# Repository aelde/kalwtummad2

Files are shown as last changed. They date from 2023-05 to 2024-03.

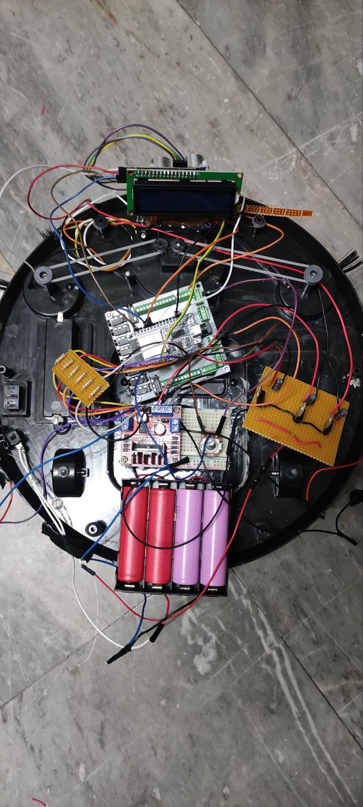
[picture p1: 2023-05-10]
model/pic/view2.jpeg

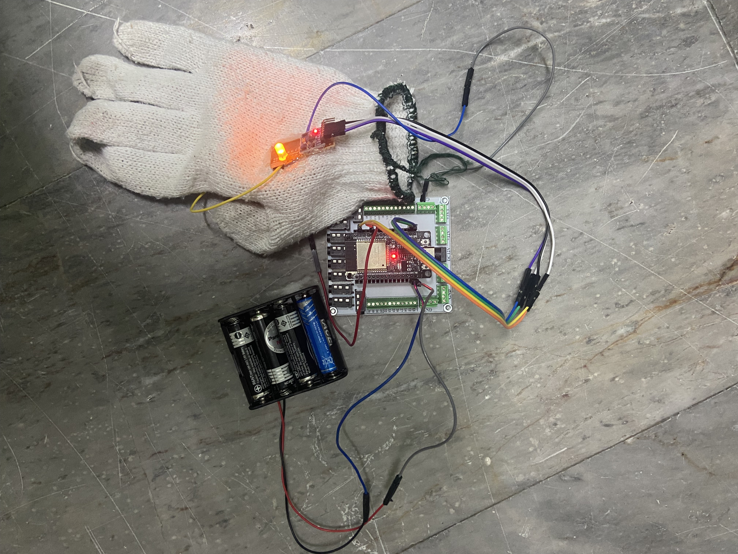
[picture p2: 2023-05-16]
model/pic/hand control.jpg

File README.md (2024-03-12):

# kalwtummad2
# mini robot


**car robot control over wifi / control over hand using mqtt**\
3d : <https://collaborate.shapr3d.com/v/xkKrqxI_4FUdMemtdK0US>

โปรเจคนี้เกิดจากความสนใจใน esp32 ของผมและพอดีช่วงนั้นอาจารย์มีหุ่นยนต์ดูดฝุ่นราคาถูกที่ไม่ได้ใช้อยู่ตัวนึง และพอดีกับที่ผมมี mpu6050 อยู่ที่บ้านพอดี ผมเลยเกิดไอเดียที่จะสร้างหุ่นยนต์ที่บังคับด้วยการขยับของมือขึ้นมา
เริ่มจากการที่แกะชิ้นส่วนทั้งหมดออกแล้วก็เอาอุปกรณ์ใหม่ใส่เข้าไปแทนหมด แล้วจากนั้นก็เชื่อมอุปกรณ์ทั้งหมดกับ esp32 จนเกิดเป็นหุ่นย์นี้ขึ้นมา(kalwtummad) โดยหุ่นย์นี้จะบังคับด้วยมือผ่าน mqtt และยังสามารถบังคับผ่านหน้า dashboard ได้ด้วย

อุปกรณ์หลักๆใน project
  - esp32
  - mpu6050
  - l298n
  - lcd1602
  - I2C liquid crystal displays

การใช้งาน : หมุนมือไปในทิศที่ต้องการจะให้รถวิ่ง ดูใน HOW_TO_USE.jpeg

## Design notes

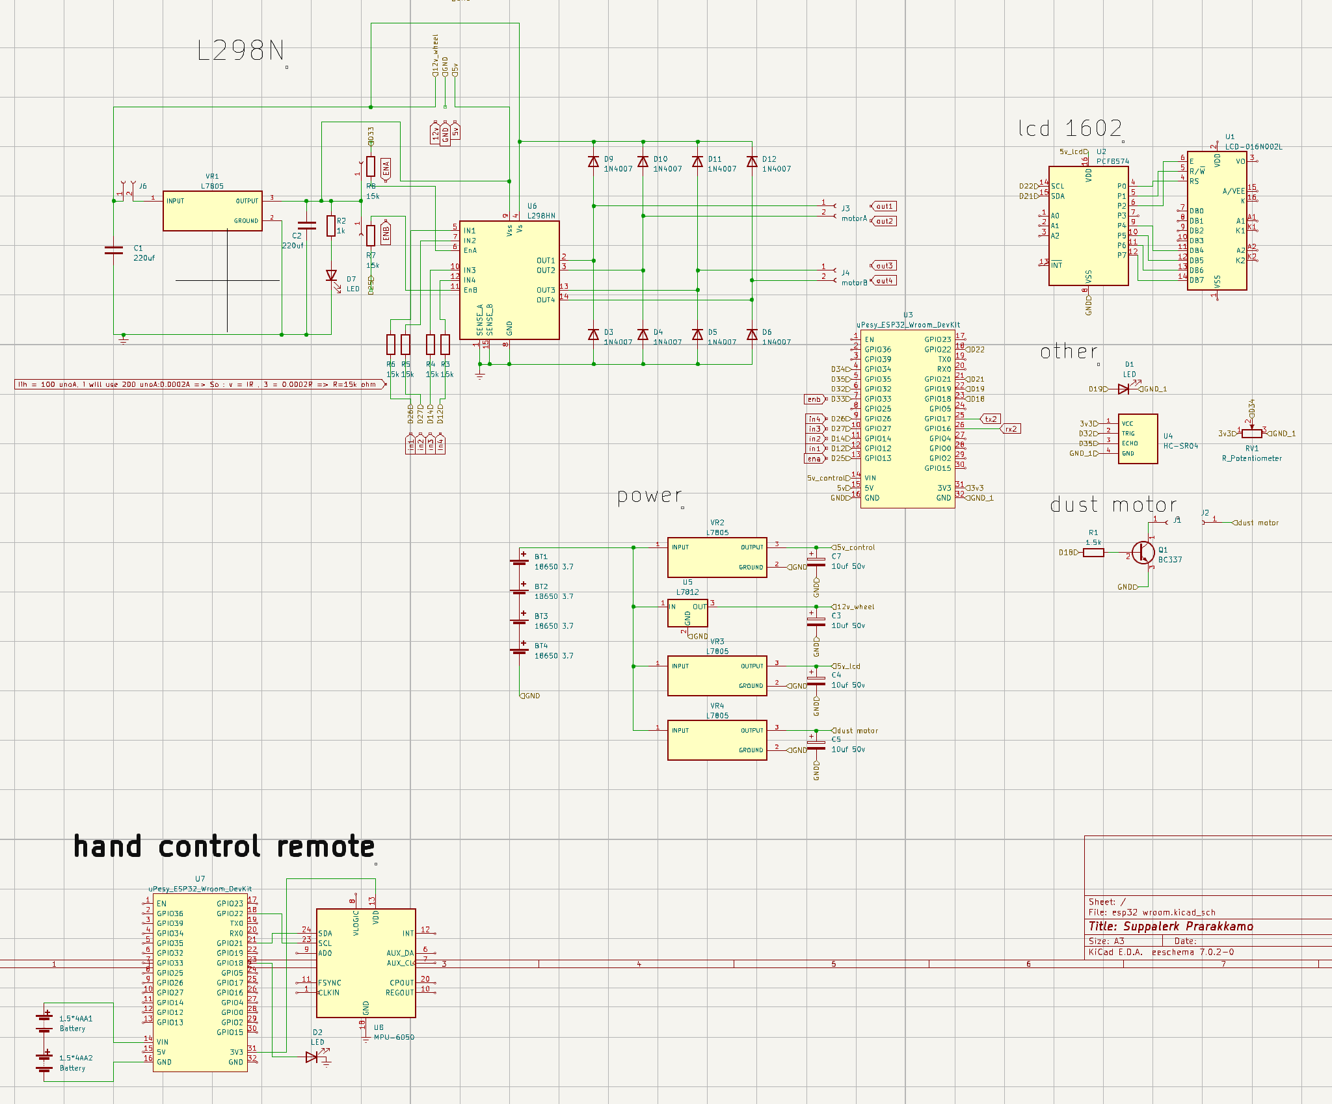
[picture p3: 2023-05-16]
model/pic/schematic updated.png

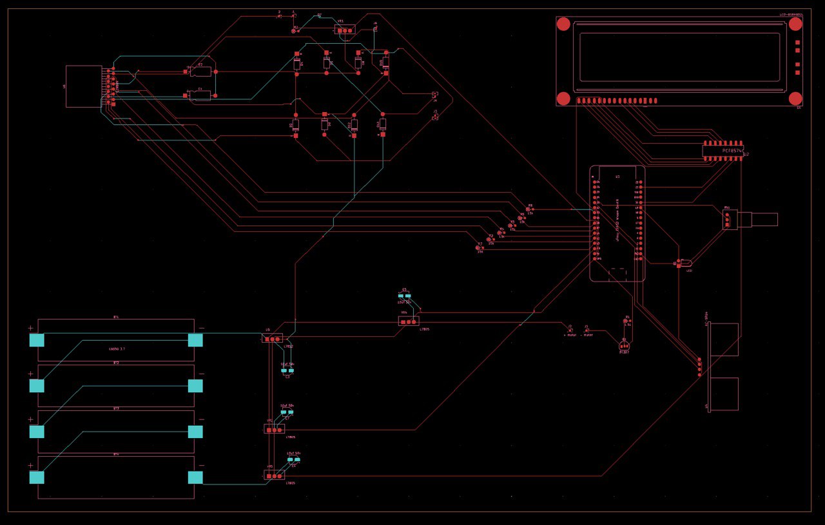
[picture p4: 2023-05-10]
model/pic/pcb.jpeg

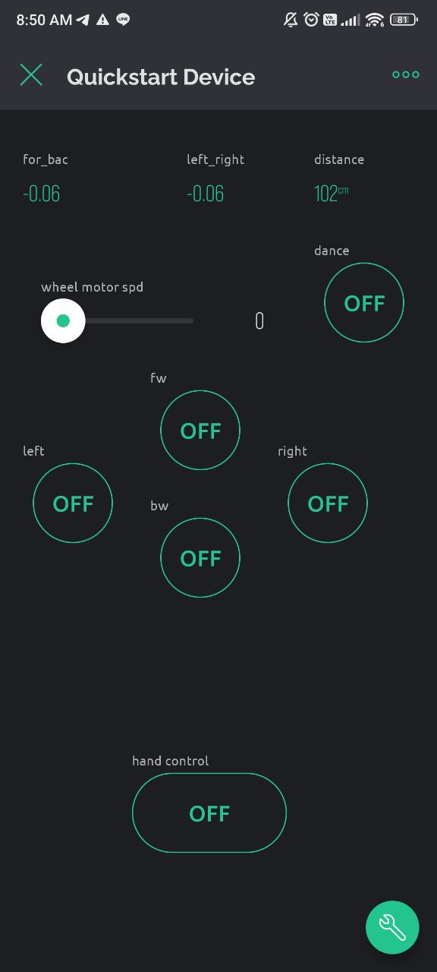
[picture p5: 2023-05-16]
model/pic/dash updated.jpeg

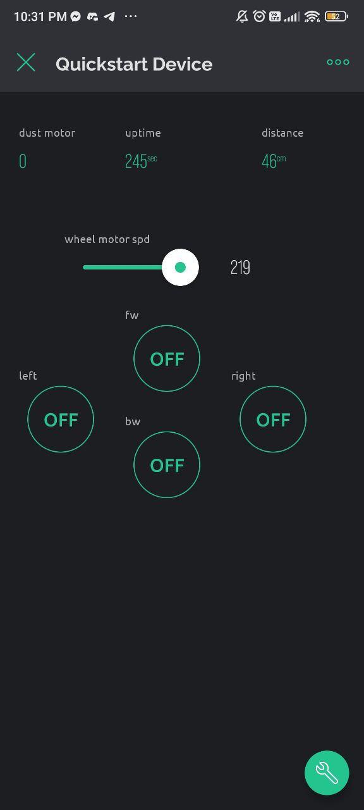
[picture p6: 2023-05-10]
model/pic/blynk dash.jpeg

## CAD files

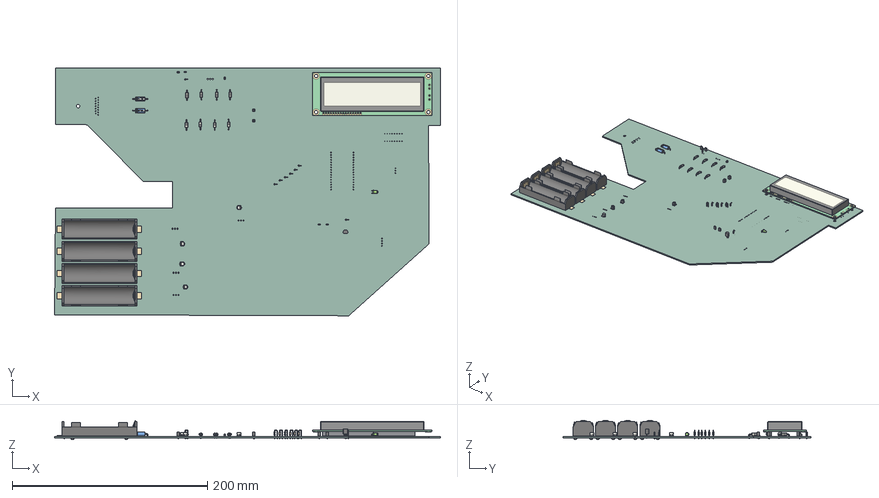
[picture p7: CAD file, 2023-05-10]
model/3d/pcb.step
395.2 x 253.5 x 19.8 mm
esp32 wroom PCB

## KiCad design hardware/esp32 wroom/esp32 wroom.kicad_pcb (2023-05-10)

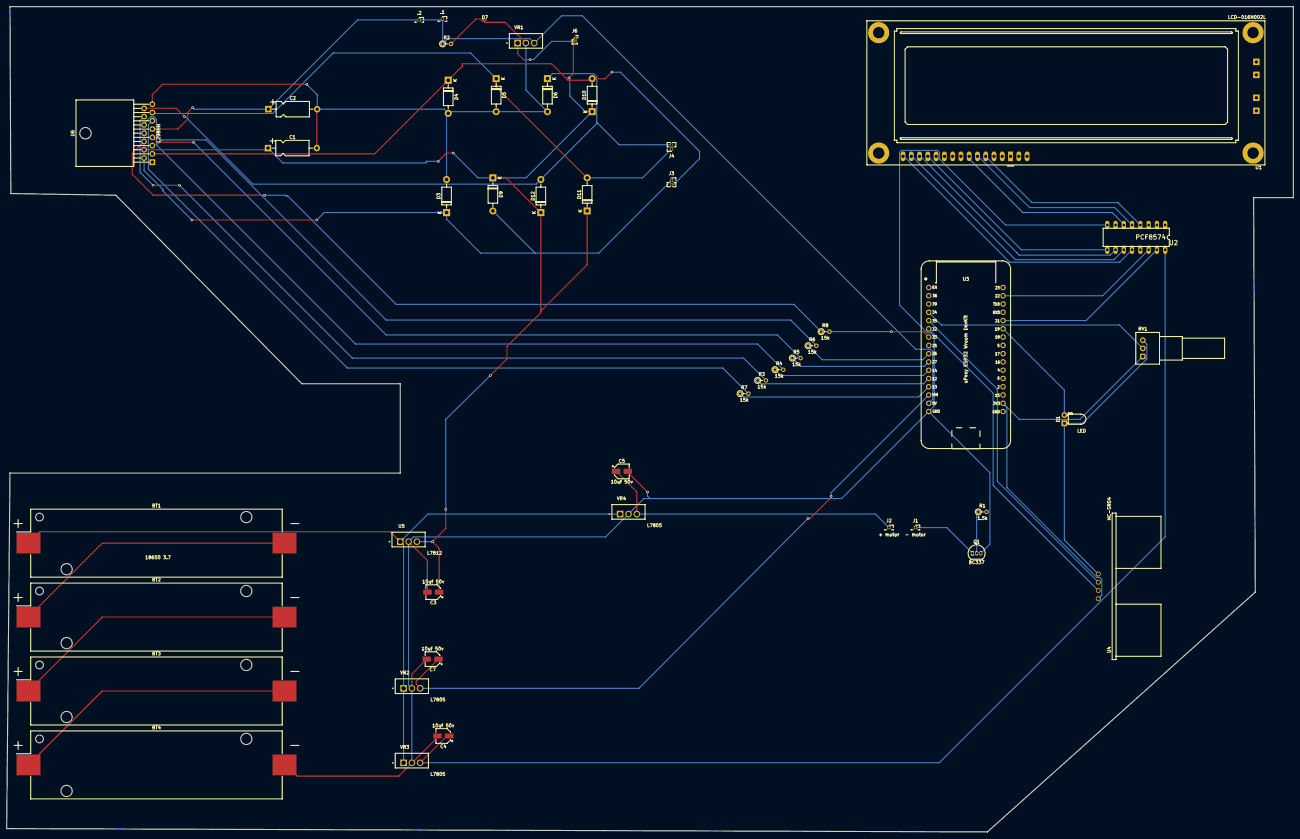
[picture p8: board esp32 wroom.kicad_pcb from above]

Board: 2 copper layers, 395.2 x 253.5 mm, 47 parts (0 on the bottom side), 47 nets.

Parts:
.1, .2: PinSocket_1x01_P1.27mm_Vertical
BT1, BT2, BT3, BT4: 18650 3.7; BatteryHolder_Keystone_1042_1x18650
C1, C2: 220uf; CP_Axial_L10.0mm_D4.5mm_P15.00mm_Horizontal
C3, C4, C5, C7: 10uf 50v; CP_Elec_4x3.9
D1: LED; LED_D3.0mm_Horizontal_O1.27mm_Z2.0mm
D3, D4, D5, D6, D9, D10, D11, D12: 1N4007; D_DO-41_SOD81_P10.16mm_Horizontal
D7: LED; LED_0201_0603Metric
J1: - motor; PinSocket_1x01_P1.27mm_Vertical
J2: + motor; PinSocket_1x01_P1.27mm_Vertical
J3: motorA; PinSocket_1x02_P1.27mm_Vertical
J4: motorB; PinSocket_1x02_P1.27mm_Vertical
J6: PinSocket_1x02_P1.00mm_Vertical
Q1: BC337; TO-92_Inline
R1: 1.5k; R_Axial_DIN0204_L3.6mm_D1.6mm_P2.54mm_Vertical
R2: 1k; R_Axial_DIN0204_L3.6mm_D1.6mm_P2.54mm_Vertical
R3, R4, R5, R6, R7, R8: 15k; R_Axial_DIN0204_L3.6mm_D1.6mm_P2.54mm_Vertical
RV1: R_Potentiometer; Potentiometer_Alps_RK097_Single_Horizontal
U1: LCD-016N002L
U2: PCF8574; DIL16
U3: uPesy_ESP32_Wroom_DevKit
U4: HC-SR04
U5: L7812; L7805
U6: L298HN; TO-220-15_P2.54x2.54mm_StaggerOdd_Lead5.84mm_TabDown
VR1, VR2, VR3, VR4: L7805

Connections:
5v: .1.1, .2.1, C2.1, R2.1, U3.15 (5V), U6.9 (Vss), VR1.3 (OUTPUT)
/3v3: RV1.1, U3.31 (3V3), U4.1 (VCC)
/5v_control: C7.1, U3.14 (VIN), VR2.3 (OUTPUT)
/5v_lcd: C4.1, U2.16 (VDD), VR3.3 (OUTPUT)
/12v_wheel: C1.1, C3.1, D9.1 (K), D10.1 (K), D11.1 (K), D12.1 (K), J6.1, U5.3 (OUT), U6.4 (Vs)
/D12: R3.1, U3.12 (GPIO12)
/D14: R4.1, U3.11 (GPIO14)
/D18: R1.2, U3.23 (GPIO18)
/D19: D1.2 (A), U3.22 (GPIO19)
/D21: U2.15 (SDA), U3.21 (GPIO21)
/D22: U2.14 (SCL), U3.18 (GPIO22)
/D25: R7.1, U3.13 (GPIO13)
/D26: R6.1, U3.9 (GPIO26)
/D27: R5.1, U3.10 (GPIO27)
/D32: U3.6 (GPIO32), U4.2 (TRIG)
/D33: R8.2, U3.7 (GPIO33)
/D34: RV1.2, U3.4 (GPIO34)
/D35: U3.5 (GPIO35), U4.3 (ECHO)
/GND_1: D1.1 (K), RV1.3, U3.32 (GND), U4.4 (GND)
/dust motor: C5.1, J2.1, VR4.3 (OUTPUT)
Earth: C1.2, C2.2, D3.2 (A), D4.2 (A), D5.2 (A), D6.2 (A), D7.1 (K), U6.1 (SENSE_A), U6.8 (GND), U6.15 (SENSE_B), VR1.2 (GROUND)
GND: BT4.2 (-), C3.2, C4.2, C5.2, C7.2, Q1.3 (E), U2.8 (VSS), U3.16 (GND), U5.2 (GND), VR2.2 (GROUND), VR3.2 (GROUND), VR4.2 (GROUND)
unnamed: BT1.1 (+), U5.1 (IN), VR2.1 (INPUT), VR3.1 (INPUT), VR4.1 (INPUT)
unnamed: BT1.2 (-), BT2.1 (+)
unnamed: BT2.2 (-), BT3.1 (+)
unnamed: BT3.2 (-), BT4.1 (+)
unnamed: D3.1 (K), D9.2 (A), J3.1, U6.2 (OUT1)
unnamed: D7.2 (A), R2.2
unnamed: D4.1 (K), D10.2 (A), J3.2, U6.3 (OUT2)
unnamed: D5.1 (K), D11.2 (A), J4.1, U6.13 (OUT3)
unnamed: D6.1 (K), D12.2 (A), J4.2, U6.14 (OUT4)
unnamed: J1.1, Q1.1 (C)
unnamed: J6.2, VR1.1 (INPUT)
unnamed: Q1.2 (B), R1.1
unnamed: U1.11 (DB4), U2.9 (P4)
unnamed: U1.12 (DB5), U2.10 (P5)
unnamed: U1.13 (DB6), U2.11 (P6)
unnamed: U1.14 (DB7), U2.12 (P7)
unnamed: U1.6 (E), U2.6 (P2)
unnamed: U1.4 (RS), U2.4 (P0)
unnamed: U1.5 (R/~W), U2.5 (P1)
unnamed: R8.1, U6.6 (EnA)
unnamed: R7.2, U6.11 (EnB)
unnamed: R6.2, U6.5 (IN1)
unnamed: R5.2, U6.7 (IN2)
unnamed: R4.2, U6.10 (IN3)
unnamed: R3.2, U6.12 (IN4)

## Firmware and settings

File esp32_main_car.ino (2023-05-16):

#include <Arduino.h>
#include <LiquidCrystal_I2C.h>
#include "LittleFS.h"
#include <WiFiClientSecure.h>
#include <PubSubClient.h>

char msg[150];
long lastMsg = 0;
float x=0,y=0;

//mpu6050 import from another esp32 with blynk
int hand_control = 0;
float for_bac = 0; 
float left_right = 0;

// setup pin
long int duration;
int distance = 0;

// MQTT netpie  device 2 **********************
const char* mqtt_server = "broker.netpie.io";
const int mqtt_port = 1883;
const char* mqtt_Client = "";
const char* mqtt_username = "";
const char* mqtt_password = "";

WiFiClient espClient;
PubSubClient client(espClient);

void callback(char* topic, byte* payload, unsigned int length) {
  // Serial.print("Message arrived [");
  // Serial.print(topic);
  // Serial.print("] ");
  String message;
  for (int i = 0; i < length; i++) {
    message = message + (char)payload[i];
  }
  if (String(topic) == "@msg/test") {
    for_bac = message.toFloat();
  } else if (String(topic) == "@msg/test2") {
    left_right = message.toFloat();
  }
}

void reconnect() {
  while (!client.connected()) {
    Serial.print("Attempting NETPIE2020 connection…");
    if (client.connect(mqtt_Client, mqtt_username, mqtt_password)) {
      Serial.println("NETPIE2020 connected");
      // client.subscribe("@msg/led");
      client.subscribe("@msg/#");
      // client.subscribe("@msg/test2");
      
    }
    else {
      Serial.print("failed, rc=");
      Serial.print(client.state());
      Serial.println("try again in 5 seconds");
      delay(5000);
    }
  }
}
// **********************************************************************************************************************************************************

// wheel motor l298n
int wheel_spd = 0;
int enA = 13; // 12 // 33  // 13
int in1 = 12; // 14 // 26  // 12
int in2 = 14; // 13 // 27  // 14
int in3 = 27; // 26 // 14  // 26
int in4 = 26; // 33 // 12  // 33
int enB = 33; // 27 // 13  // 27

// status robot control move forward, backward, left, right, autopilot
int fw = 0, bw = 0, right = 0, left = 0, autopilot = 0;

// potentiometer
int pot = 34;
int pwm = 0;

// Lcd
int scl = 22;
int sda = 21;
LiquidCrystal_I2C lcd(0x27, 16, 2); // 0x27 for PCF8574 and 0x3F for PCF8574A

// ultrasonic
int t = 32;
int e = 35;

int led1 = 19;
int dust = 18; 

// dance mode
int dance = 0;

void lcdsetup(){
  lcd.init();
  lcd.backlight();
}
void lcdrefresh(int agr, int lcdrow){
  float lcdcon = agr/10;
  if(lcdcon < 1){lcd.setCursor(5,lcdrow);}
  else if(lcdcon < 10){lcd.setCursor(6,lcdrow);}
  else if(lcdcon < 100){lcd.setCursor(7,lcdrow);}
  else if(lcdcon < 1000){lcd.setCursor(8,lcdrow);}
  lcd.print("                ");
}
void move(int fw, int bw, int right, int left){
  if(fw == 1){
    Serial.println("move forward");
    analogWrite(enA, wheel_spd);
    analogWrite(enB, wheel_spd);
    digitalWrite(in1, 1);
    digitalWrite(in2, 0);
    digitalWrite(in3, 1);
    digitalWrite(in4, 0);
  }
  else if(bw == 1){
    Serial.println("move backward");
    analogWrite(enA, wheel_spd);
    analogWrite(enB, wheel_spd);
    digitalWrite(in1, 0);
    digitalWrite(in2, 1);
    digitalWrite(in3, 0);
    digitalWrite(in4, 1);
  }
  else if(right == 1){
    Serial.println("move right");
    analogWrite(enA, wheel_spd);
    analogWrite(enB, wheel_spd);
    digitalWrite(in1, 0);
    digitalWrite(in2, 1);
    digitalWrite(in3, 1);
    digitalWrite(in4, 0);
  }
  else if(left == 1){
    Serial.println("move left");
    analogWrite(enA, wheel_spd);
    analogWrite(enB, wheel_spd);
    digitalWrite(in1, 1);
    digitalWrite(in2, 0);
    digitalWrite(in3, 0);
    digitalWrite(in4, 1);
  } else if (dance == 1){
      for (int i = 0; i < 3; i++) {
          digitalWrite(led1, HIGH);
          delay(250);
          digitalWrite(led1, LOW);
          delay(250);
      }
    Serial.println("dance");
    analogWrite(enA, 240);
    analogWrite(enB, 240);
    // spin
    digitalWrite(in1, 1);
      digitalWrite(led1,HIGH);
    digitalWrite(in2, 0);
      digitalWrite(led1,LOW);
    digitalWrite(in3, 0);
      digitalWrite(led1,HIGH);
    digitalWrite(in4, 1);
    delay(4000);

    digitalWrite(led1,LOW);
    // spin
    digitalWrite(in1, 0);
    digitalWrite(led1,HIGH);
    digitalWrite(in2, 1);
    digitalWrite(led1,LOW);
    digitalWrite(in3, 1);
    digitalWrite(led1,HIGH);
    digitalWrite(in4, 0);
    delay(4000);

    digitalWrite(led1,LOW);
    for (int i = 0; i < 3; i++) {
          digitalWrite(led1, HIGH);
          delay(100);
          digitalWrite(led1, LOW);
          delay(100);
      }
    // forward a  bit
    digitalWrite(in1, 1);
    digitalWrite(in2, 0);
    digitalWrite(in3, 1);
    digitalWrite(in4, 0);
      delay(1000);

    for (int i = 0; i < 5; i++) {
          digitalWrite(led1, HIGH);
          delay(50);
          digitalWrite(led1, LOW);
          delay(50);
      }
      digitalWrite(led1,HIGH);
    // backward a bit
    digitalWrite(in1, 0);
    digitalWrite(in2, 1);
    digitalWrite(in3, 0);
    digitalWrite(in4, 1);
      delay(1000);
      digitalWrite(led1,LOW);

  }
  else{
    Serial.println("stop");
    analogWrite(enA, 0);
    analogWrite(enB, 0);
    digitalWrite(in1, LOW);
    digitalWrite(in2, LOW);
    digitalWrite(in3, LOW);
    digitalWrite(in4, LOW);
  }
}
void hand_controller(){
    if (abs(for_bac) >= abs(left_right)){
        wheel_spd = abs(for_bac);
        if (for_bac > 0){
            fw = 1;
            bw = 0;
            right = 0;
            left = 0;
            dance = 0;
        } else {
            fw = 0;
            bw = 1;
            right = 0;
            left = 0;
            dance = 0;
        }
    } else {
        wheel_spd = abs(left_right);
        if (left_right > 0){
            fw = 0;
            bw = 0;
            right = 1;
            left = 0;
            dance = 0;
        } else {
            fw = 0;
            bw = 0;
            right = 0;
            left = 1;
            dance = 0;
        }
    }
    move(fw, bw, right, left);
    Serial.println("Wheel speed : "+String(wheel_spd));

}
// **********************************************************************************************************************************************************
/*************************************************************

  This is a simple demo of sending and receiving some data.
  Be sure to check out other examples!
 *************************************************************/

/* Fill-in information from Blynk Device Info here */
#define BLYNK_TEMPLATE_ID           ""
#define BLYNK_TEMPLATE_NAME         ""
#define BLYNK_AUTH_TOKEN            ""

/* Comment this out to disable prints and save space */
#define BLYNK_PRINT Serial


#include <WiFi.h>
#include <WiFiClient.h>
#include <BlynkSimpleEsp32.h>

// Your WiFi credentials.

//char ssid[] = "SIAM_WIFI";
//char pass[] = "";

BlynkTimer timer;

// This function is called every time the Virtual Pin 0 state changes
BLYNK_WRITE(V0)
{
  // Set incoming value from pin V0 to a variable
  int value = param.asInt();
  dance = value;
}
BLYNK_WRITE(V4)
{
  // Set incoming value from pin V0 to a variable
  int value = param.asInt();
  wheel_spd = value;
}
BLYNK_WRITE(V6)
{
  // Set incoming value from pin V0 to a variable
  int value = param.asInt();
  fw = value;
}
BLYNK_WRITE(V7)
{
  // Set incoming value from pin V0 to a variable
  int value = param.asInt();
  bw = value;
}
BLYNK_WRITE(V8)
{
  // Set incoming value from pin V0 to a variable
  int value = param.asInt();
  left = value;
}
BLYNK_WRITE(V9)
{
  // Set incoming value from pin V0 to a variable
  int value = param.asInt();
  right = value;
}

// hand control
BLYNK_WRITE(V1)
{
  // Set incoming value from pin V0 to a variable
  int value = param.asInt();
  hand_control = value;
}
// BLYNK_WRITE(V2)
// {
//   // Set incoming value from pin V0 to a variable
// //   int value = param.asInt();
//   double value = param.asDouble();
//   for_bac = value;
// }
// BLYNK_WRITE(V5)
// {
//   // Set incoming value from pin V0 to a variable
//     //   int value = param.asInt();
//     double value = param.asDouble();
//     left_right = value;
// }

// This function is called every time the device is connected to the Blynk.Cloud
// BLYNK_CONNECTED()
// {
//   // Change Web Link Button message to "Congratulations!"
//   Blynk.setProperty(V3, "offImageUrl", "https://static-image.nyc3.cdn.digitaloceanspaces.com/general/fte/congratulations.png");
//   Blynk.setProperty(V3, "onImageUrl",  "https://static-image.nyc3.cdn.digitaloceanspaces.com/general/fte/congratulations_pressed.png");
//   Blynk.setProperty(V3, "url", "https://docs.blynk.io/en/getting-started/what-do-i-need-to-blynk/how-quickstart-device-was-made");
// }

// This function sends Arduino's uptime every second to Virtual Pin 2.
void myTimerEvent()
{
  // You can send any value at any time.
  // Please don't send more that 10 values per second.
  // Blynk.virtualWrite(V2, millis() / 1000);
  // Blynk.virtualWrite(V5, pwm);
  Blynk.virtualWrite(V3, distance);
}

// **********************************************************************************************************************************************************
void setup(){
  Serial.begin(115200);
  Serial.println("setup...");
  // blink setup ***********
  Blynk.begin(BLYNK_AUTH_TOKEN, ssid, pass);
  // You can also specify server:
  // Blynk.begin(BLYNK_AUTH_TOKEN, ssid, pass, "blynk.cloud", 80);
  // Blynk.begin(BLYNK_AUTH_TOKEN, ssid, pass, "blynk.cloud", 8080);
  // Setup a function to be called every second
  timer.setInterval(1000L, myTimerEvent);
  // ***********************

    // mqtt setup ************
    client.setServer(mqtt_server, mqtt_port);
    client.setCallback(callback);
    // ***********************

//   pinMode(dust, OUTPUT);
  pinMode(enA, OUTPUT);
  pinMode(enB, OUTPUT);
  pinMode(in1, OUTPUT);
  pinMode(in2, OUTPUT);
  pinMode(in3, OUTPUT);
  pinMode(in4, OUTPUT);

  pinMode(scl, OUTPUT);
  pinMode(sda, OUTPUT);
  pinMode(t, OUTPUT);
  pinMode(e, INPUT);
  pinMode(led1, OUTPUT);

  lcdsetup();
    for (int i = 0; i < 5; i++) {
    digitalWrite(led1, HIGH);
    delay(250);
    digitalWrite(led1, LOW);
    delay(250);
    }

  Serial.println("setup...end");
}
void loop(){
    //   Serial.println("loop...");
    Blynk.run();
    //   Serial.println("Blynk.run()...end");
    // Serial.println("wheel : "+String(wheel_spd));
    timer.run();

    if (for_bac > 250){for_bac = 250;}
    if (for_bac < -250){for_bac = -250;}
    if (left_right > 250){left_right = 250;}
    if (left_right < -250){left_right = -250;}
    
    if (!client.connected()) {
        reconnect();
    }
    client.loop();

    long now = millis();

    if (now - lastMsg > 500) {
    Serial.println("for_bac : "+String(abs(for_bac)));
    Serial.println("left_right : "+String(abs(left_right)));
    lastMsg = now;
    }
    delay(1); 

  // analogWrite(enA, wheel_spd);
  // digitalWrite(in1, 1);
  // digitalWrite(in2, 0);

    digitalWrite(t, LOW);
    delayMicroseconds(2);
    // Sets the trigPin on HIGH state for 10 micro seconds
    digitalWrite(t, HIGH);
    delayMicroseconds(10);
    digitalWrite(t, LOW);
    // Reads the echoPin, returns the sound wave travel time in microseconds
    duration = pulseIn(e, HIGH);
    // Calculating the distance
    distance = duration * 0.034 / 2;
    //   Serial.print("Distance: ");
    //   Serial.println(distance);

    // function to real time update the distance ไม่ให้ตัวเลขทับกัน
    lcdrefresh(distance, 1);
    if(distance < 15){
        digitalWrite(led1, HIGH);
    }
    else{
        digitalWrite(led1, LOW);
    }
    lcd.setCursor(0, 1);
    lcd.print("Dis:");
    lcd.print(distance);

    //   int p = analogRead(pot);
    //   pwm = map(p, 0, 4095, 0, 255);
    //   Serial.print("PWM:");
    //   Serial.println(pwm);
    lcdrefresh(wheel_spd, 0);
    lcd.setCursor(0, 0);
    lcd.print("SPD:");
    lcd.print(wheel_spd);

    //   Serial.println("move...");
    Serial.println("hand_control : "+String(hand_control));
    if (hand_control == 1)
    {
        // Serial.println("hand control...");
        hand_controller();
        Serial.println("for_bac : "+String(for_bac));
        Serial.println("left_right : "+String(left_right));
    } else {
        move(fw, bw, right, left);
        // move(fw, bw, right, left);

    }
    
    //   Serial.println("move...end");
    
    // digitalWrite(led1, HIGH);
    
    //   analogWrite(dust, pwm);

    // Serial.println("a:" + String((dust)));
    // ledcAttachPin(dust, pwm);
    //   Serial.println("loop...end");
    delay(1);
}

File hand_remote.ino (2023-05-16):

#include <WiFiClientSecure.h>
#include <Wire.h>
#include <PubSubClient.h>
#include <WiFi.h>

int led = 18;
char msg[150];

// MQTT netpie device 3 **********************
const char* mqtt_server = "broker.netpie.io";
const int mqtt_port = 1883;
const char* mqtt_Client = "";
const char* mqtt_username = "";
const char* mqtt_password = "";

WiFiClient espClient;
PubSubClient client(espClient);

void reconnect() {
  while (!client.connected()) {
    Serial.print("Attempting NETPIE2020 connection…");
    if (client.connect(mqtt_Client, mqtt_username, mqtt_password)) {
      Serial.println("NETPIE2020 connected");
    } else {
      Serial.print("failed, rc=");
      Serial.print(client.state());
      Serial.println("try again in 5 seconds");
      delay(5000);
    }
  }
}

// mpu 6050
float RateRoll, RatePitch, RateYaw;
float AccX, AccY, AccZ;
float AngleRoll, AnglePitch;
float LoopTimer;

double x = 0, y = 0, z = 0;

int pot = 34;
int a = 0;

// mp6050 setup
void gyro_signals(void) {
  Wire.beginTransmission(0x68);
  Wire.write(0x1A);
  Wire.write(0x05);
  Wire.endTransmission();
  Wire.beginTransmission(0x68);
  Wire.write(0x1C);
  Wire.write(0x10);
  Wire.endTransmission();
  Wire.beginTransmission(0x68);
  Wire.write(0x3B);
  Wire.endTransmission();
  Wire.requestFrom(0x68, 6);
  int16_t AccXLSB = Wire.read() << 8 | Wire.read();
  int16_t AccYLSB = Wire.read() << 8 | Wire.read();
  int16_t AccZLSB = Wire.read() << 8 | Wire.read();
  Wire.beginTransmission(0x68);
  Wire.write(0x1B);
  Wire.write(0x8);
  Wire.endTransmission();
  Wire.beginTransmission(0x68);
  Wire.write(0x43);
  Wire.endTransmission();
  Wire.requestFrom(0x68, 6);
  int16_t GyroX = Wire.read() << 8 | Wire.read();
  int16_t GyroY = Wire.read() << 8 | Wire.read();
  int16_t GyroZ = Wire.read() << 8 | Wire.read();
  RateRoll = (float)GyroX / 65.5;
  RatePitch = (float)GyroY / 65.5;
  RateYaw = (float)GyroZ / 65.5;
  AccX = (float)AccXLSB / 4096;
  AccY = (float)AccYLSB / 4096;
  AccZ = (float)AccZLSB / 4096;
  AngleRoll = atan(AccY / sqrt(AccX * AccX + AccZ * AccZ)) * 1 / (3.142 / 180);
  AnglePitch = -atan(AccX / sqrt(AccY * AccY + AccZ * AccZ)) * 1 / (3.142 / 180);
}
// *************************************************************/

// Your WiFi credentials.
// char ssid[] = "SIAM_WIFI";
// char pass[] = "";

void setup() {
  Serial.begin(115200);
  pinMode(led,OUTPUT);
  // mpu6050 setup
  Wire.setClock(400000);
  Wire.begin();
  delay(250);
  Wire.beginTransmission(0x68);
  Wire.write(0x6B);
  Wire.write(0x00);
  Wire.endTransmission();

  Serial.begin(115200);
  Serial.println("Starting...");
  if (WiFi.begin(ssid, password)) {
    while (WiFi.status() != WL_CONNECTED) {
      delay(1000);
      Serial.print(".");
    }
  }
  Serial.println("WiFi connected");
  Serial.println("IP address: ");
  Serial.println(WiFi.localIP());

  // MQTT netpie **********************
  client.setServer(mqtt_server, mqtt_port);
  digitalWrite(led,1);
  // ***********************
}
void loop()
{   
    digitalWrite(led,1);
    gyro_signals();

    double xx = map(AccX,-1,1,-255,255);
    double yy = map(AccY,-1,1,-255,255);
    double zz = map(AccZ,-1,1,-255,255);

    x = AccX*255;
    y = AccY*255;
    z = AccZ*255;

    if (!client.connected()) {
      digitalWrite(led,0);
    reconnect();
    }
    client.loop();

    // String data = "{\"data\": {\"xValue\":" + String(x) + ", \"yValue\":" + String(x) + "}}";
    // String data = "{\"x\": ["String(x)", "String(y)"]}";
    // String data = "{\"x\":" + String(x) + ", \"y\":" + String(y) + "}";

    // Serial.println(data);
    // data.toCharArray(msg, (data.length() + 1));
    // client.publish("@shadow/data/update", msg);
    // client.publish("@msg/test3", msg);

    
    client.publish("@msg/test",String(x).c_str());
    // client.publish("@msg/test","x222");
    delay(10);
    client.publish("@msg/test2",String(y).c_str());
    // client.publish("@msg/test2","y333");

    // Serial.println("Hello Netpie2020");
    delay(250); 

    Serial.print("Acceleration X [g]= ");
    // Serial.print(AccX);
    // Serial.print(xx);
    Serial.print(x);
    Serial.print(" Acceleration Y [g]= ");
    // Serial.print(AccY);
    // Serial.print(yy);
    Serial.println(y);
    // Serial.print(" Acceleration Z [g]= ");
    // Serial.print(AccZ);
    // Serial.print(zz);
    // Serial.print(z);
    // Serial.print(" AngleRoll= ");
    // Serial.print(AngleRoll);
    // Serial.print(" AnglePitch= ");
    // Serial.print(AnglePitch);

    // a = analogRead(pot);
    // Serial.print("   a = ");
    // Serial.println(a);

    

    // Serial.println("dis: "+String(distance));
    delay(50);

}
